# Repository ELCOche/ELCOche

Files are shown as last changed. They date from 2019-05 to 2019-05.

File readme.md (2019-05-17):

# ELCOche
This project has been created by:
 + Mª del Pilar Aguilera Manzanera
 + Enrique Calatayud Candelas
 + Guillermo González Martín
 + María Tejedor Rami

for the subject Electronica de Comunicaciones (ELCO) at Escuela Técnica Superior
de Ingenieros de Telecomunicación (ETSIT) in the Universidad Politécnica de Madrid (UPM).

ELCOche is an educational project for schools. Students will gain Arduino programming abilities and to manage periferic modules.
The project is divided in 3 parts; First one that consists on building the car from 3D printed piezes. Second one in which the steering wheel and throttle pedal will be built. Lastly the Arduinos will be programmed for both sides transmitter(Steering wheel) and receiver(car).

[Youtube Link](https://www.youtube.com/channel/UC2VEYSTPbVNYy6-K6MgkIWw/featured)

[Instructables post](https://www.instructables.com/id/ELCOche-Remote-Control-RC-Car-Controlled-by-a-Real/)

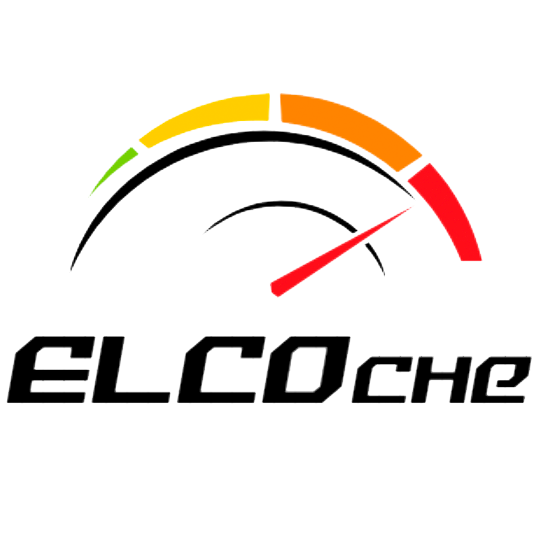
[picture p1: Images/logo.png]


[logo]: https://github.com/ELCOche/ELCOche/blob/master/Images/logo.png "Logo"

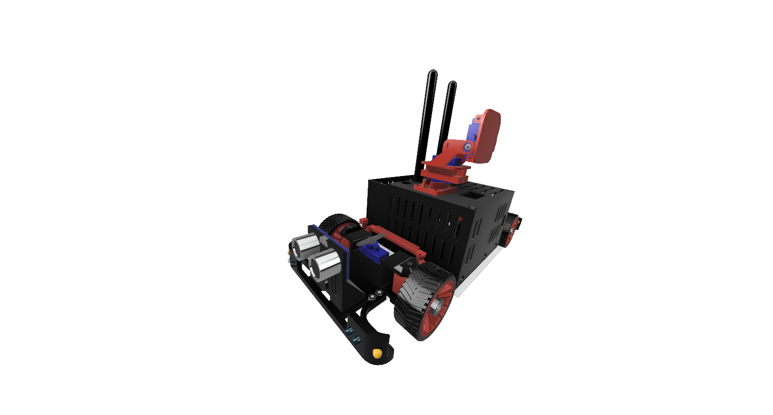
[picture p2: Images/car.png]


[car]: https://github.com/ELCOche/ELCOche/blob/master/Images/car.png "car"

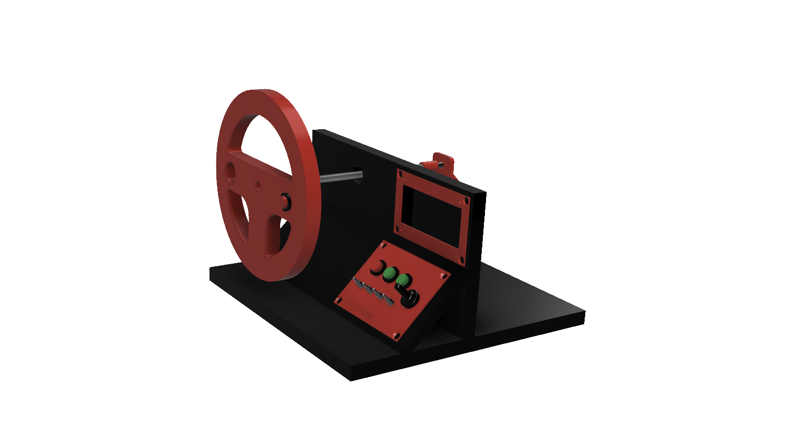
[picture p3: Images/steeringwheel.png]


[wheel]: https://github.com/ELCOche/ELCOche/blob/master/Images/steeringwheel.png "wheel"

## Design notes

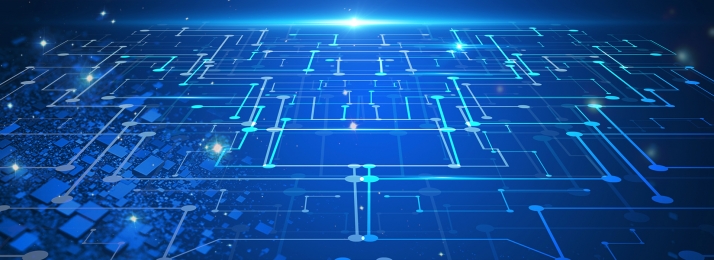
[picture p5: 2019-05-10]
Web Page/img/background/footer.jpg

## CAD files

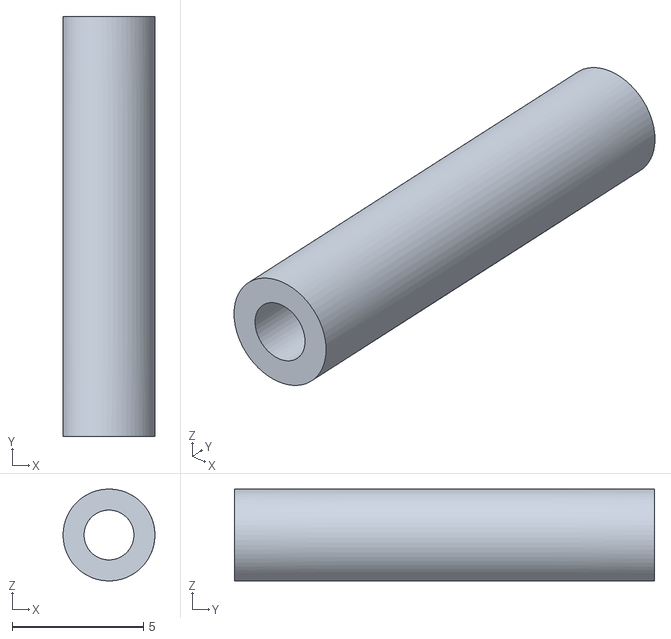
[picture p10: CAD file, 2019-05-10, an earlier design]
STL archives for 3D printing/Camera/adaptador.stl
3.50 x 16.0 x 3.50

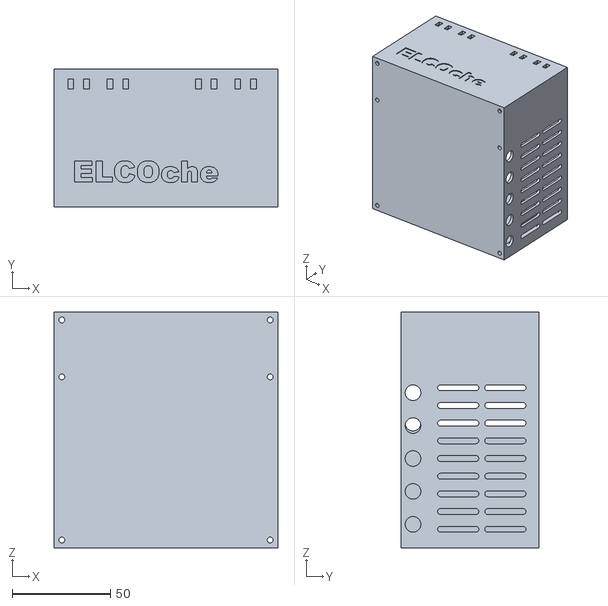
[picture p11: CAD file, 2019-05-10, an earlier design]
STL archives for 3D printing/Car/caja.stl
114.0 x 70.0 x 120.0

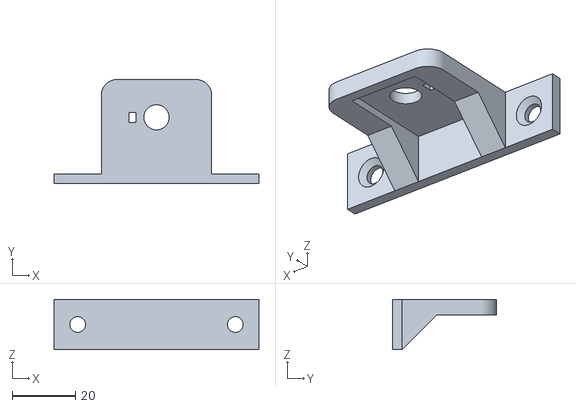
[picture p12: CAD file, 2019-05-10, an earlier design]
STL archives for 3D printing/Steering wheel/soporte_potenciometro.stl
65.0 x 33.0 x 16.0

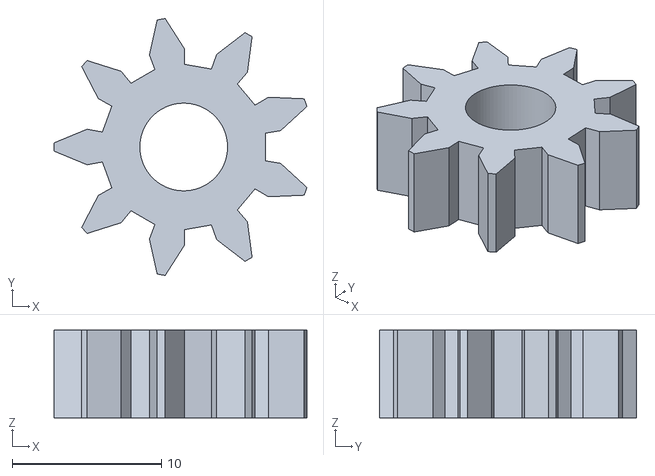
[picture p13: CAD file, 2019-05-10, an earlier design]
STL archives for 3D printing/Throttle/engranaje_potenciometro.stl
17.0 x 17.2 x 5.88

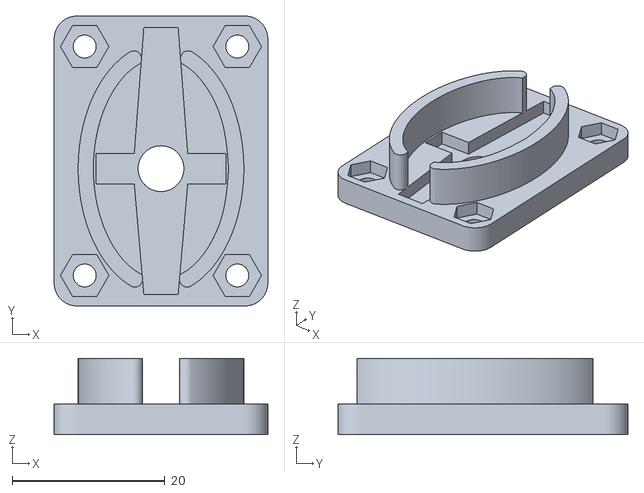
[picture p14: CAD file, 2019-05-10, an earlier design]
STL archives for 3D printing/Camera/base.stl
28.0 x 38.0 x 10.0

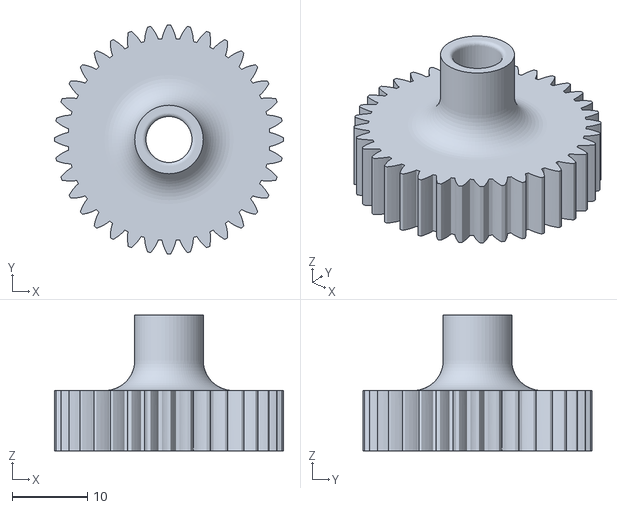
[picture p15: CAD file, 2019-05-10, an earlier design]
STL archives for 3D printing/Car/engranaje_eje.stl
30.4 x 30.4 x 18.0

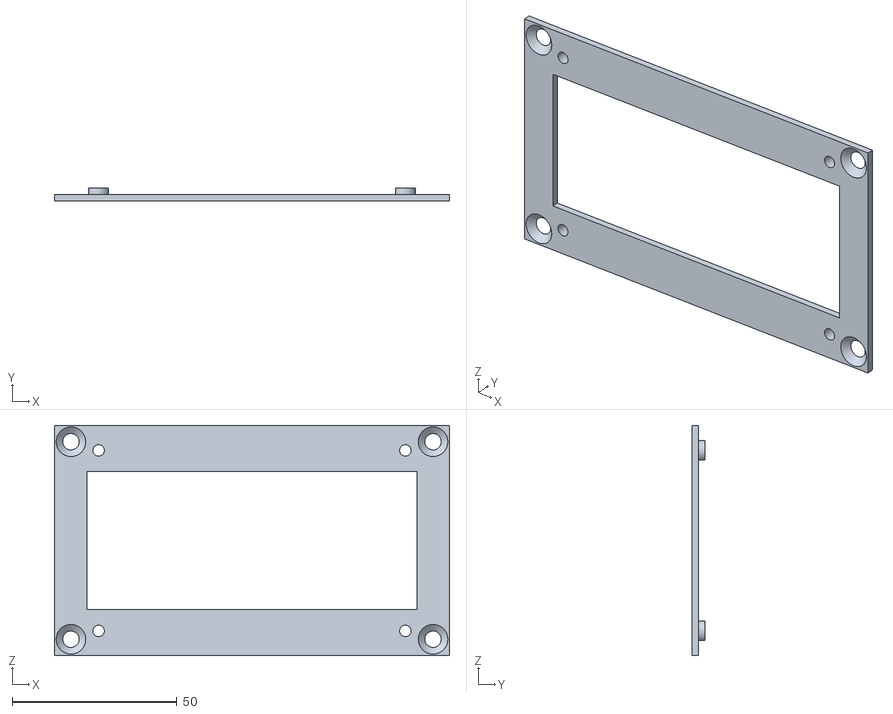
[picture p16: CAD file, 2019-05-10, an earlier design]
STL archives for 3D printing/Steering wheel/soporte_lcd.stl
120.0 x 4.00 x 70.0

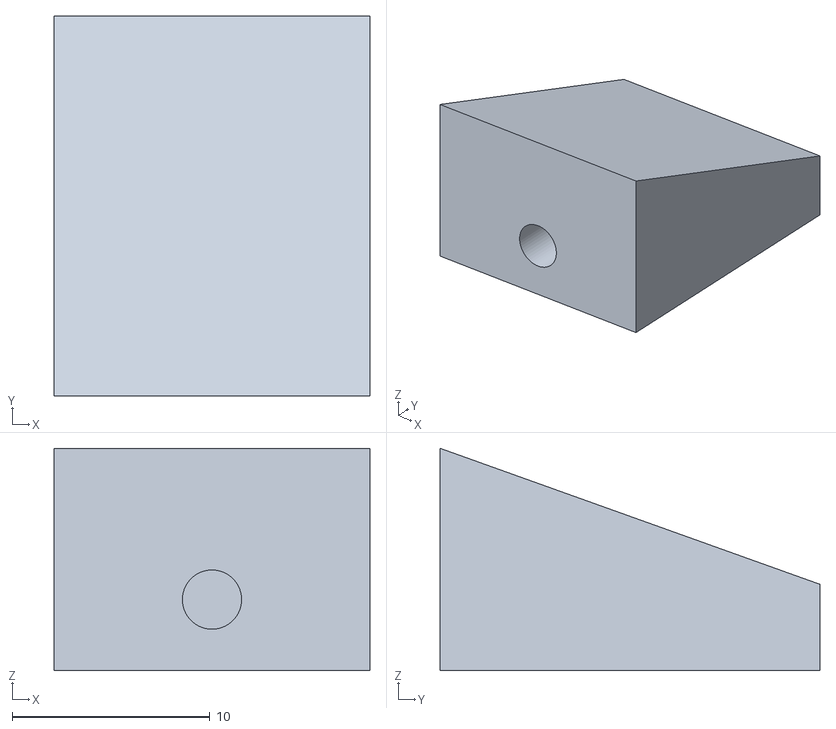
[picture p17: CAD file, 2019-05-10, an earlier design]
STL archives for 3D printing/Throttle/cuña.stl
16.0 x 19.2 x 11.3

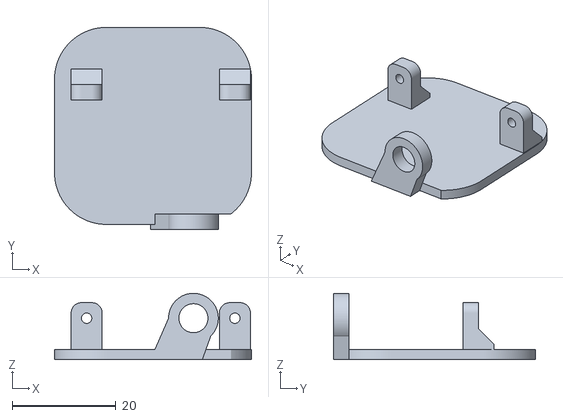
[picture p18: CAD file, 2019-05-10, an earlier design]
STL archives for 3D printing/Camera/superior.stl
38.0 x 39.0 x 12.8

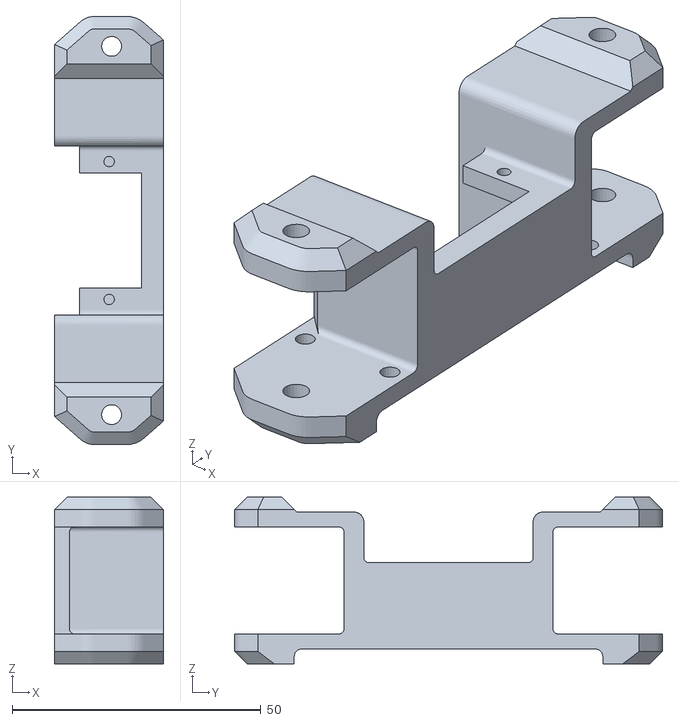
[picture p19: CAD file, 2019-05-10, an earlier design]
STL archives for 3D printing/Car/direccion.stl
21.9 x 86.0 x 33.5

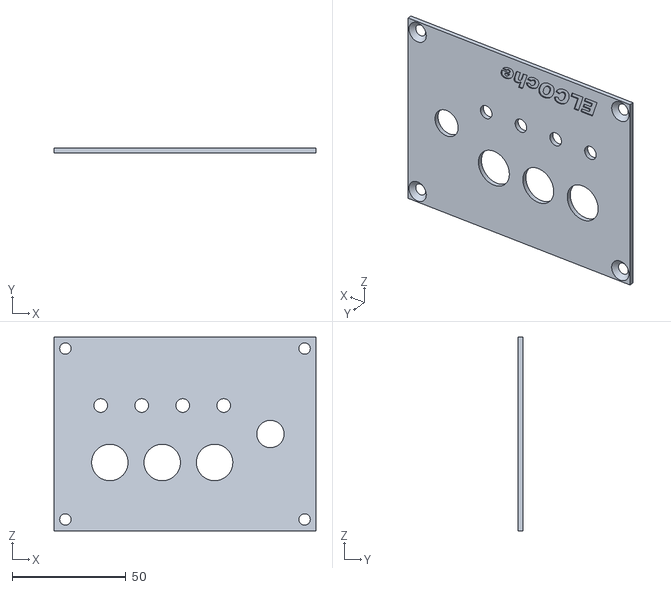
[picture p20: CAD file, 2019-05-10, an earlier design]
STL archives for 3D printing/Steering wheel/soporte_controles.stl
115.0 x 2.00 x 85.0

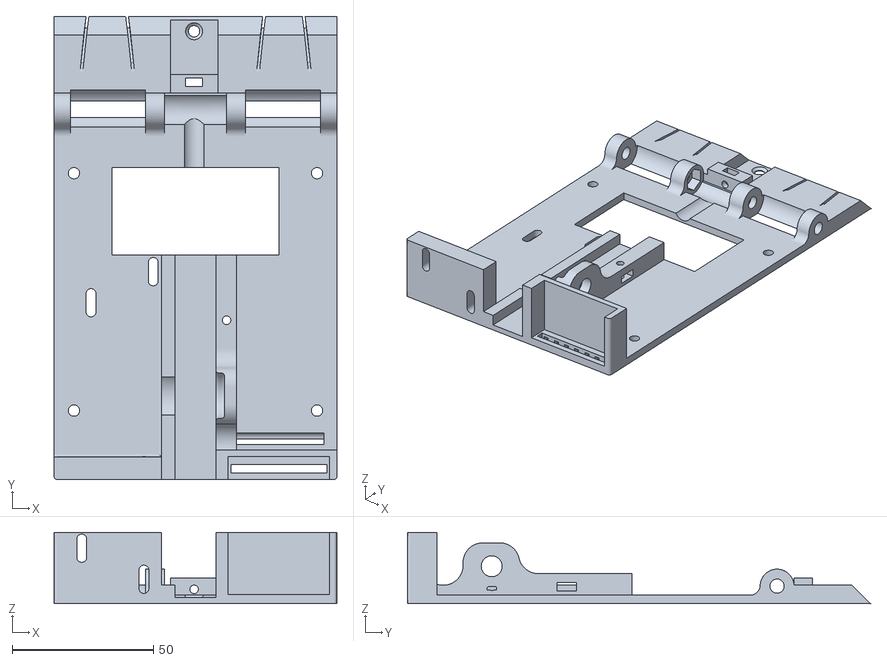
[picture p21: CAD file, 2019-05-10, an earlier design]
STL archives for 3D printing/Throttle/base.stl
100.0 x 163.8 x 25.2

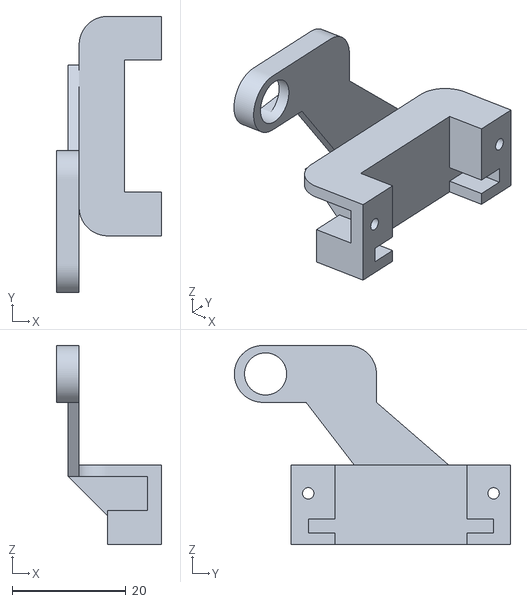
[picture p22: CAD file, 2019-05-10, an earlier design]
STL archives for 3D printing/Camera/brazo_derecho.stl
18.5 x 48.6 x 35.0

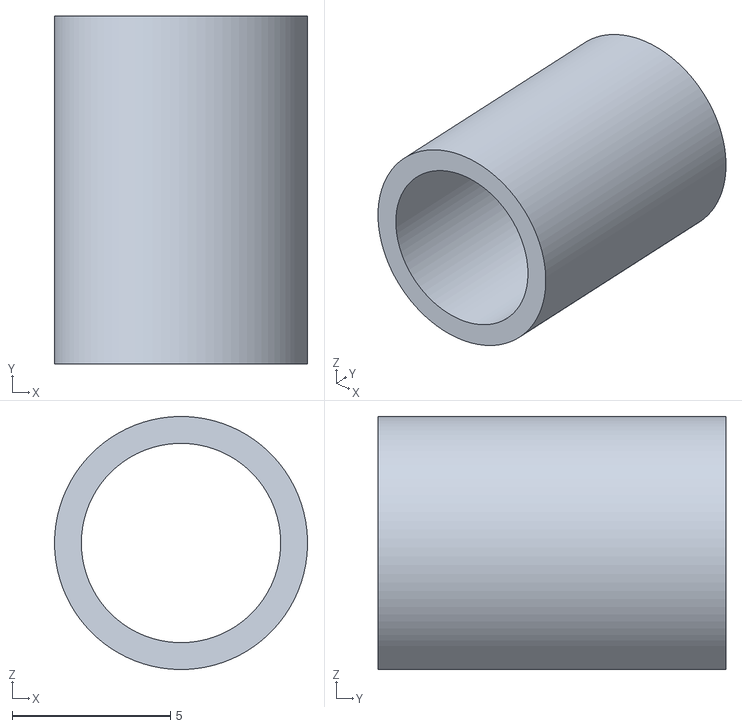
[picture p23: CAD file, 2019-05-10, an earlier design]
STL archives for 3D printing/Car/separador_rueda.stl
8.00 x 11.0 x 8.00

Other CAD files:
STL archives for 3D printing/Steering wheel/muelles.stl
STL archives for 3D printing/Throttle/brazo.stl
STL archives for 3D printing/Camera/brazo_izquierdo.stl
STL archives for 3D printing/Car/tope_rueda.stl
STL archives for 3D printing/Car/direccion_barra.stl
STL archives for 3D printing/Car/direccion_derecha.stl
STL archives for 3D printing/Car/direccion_izquierda.stl
STL archives for 3D printing/Car/direccion_objeto.stl
STL archives for 3D printing/Car/engranaje_motor.stl
STL archives for 3D printing/Car/parachoques_delantero.stl
STL archives for 3D printing/Car/parachoques_trasero.stl
STL archives for 3D printing/Car/rueda_delantera.stl
STL archives for 3D printing/Car/rueda_trasera.stl
STL archives for 3D printing/Car/soporte_eje_der.stl
STL archives for 3D printing/Car/soporte_eje_izq.stl
STL archives for 3D printing/Car/soporte_motor.stl
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

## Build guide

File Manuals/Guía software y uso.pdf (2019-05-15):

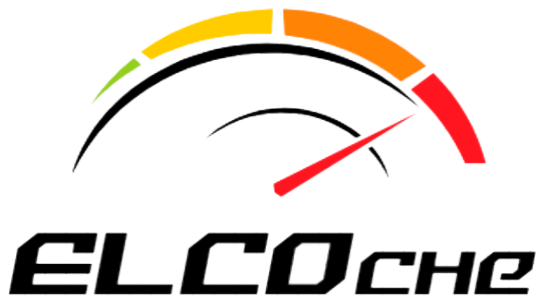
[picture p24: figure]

# Guía Software y Uso

ELCOche

## María del Pilar Aguilera Manzanera Enrique Calatayud Candelas Guillermo González Martín María Tejedor Rami

Guía de uso

## Índice de contenidos

Introducción | 3
Arduinos | 3
Programación del Transmisor | 3
Zona de configuración | 3
Envío de datos por radio | 4
Lectura de los potenciómetros | 4
Lectura de datos del acelerómetro (MPU-6050) | 5
Botones y switches | 6
Pantalla LCD | 7
Programación del Receptor | 8
Zona de configuración | 8
Recepción de datos por radio | 8
Movimiento motor | 10
Movimiento dirección | 11
Movimiento gimbal | 11
Botón de emergencia | 11
Luces del coche | 11
Sensor ultrasonido | 13
Claxon | 14
Cámara del coche | 14
Encendido y primeros pasos | 14

Guía de uso

## 1. Introducción

Guia del proyecto educativo ELCOche, diseñado para la asignatura Electrónica de consumo del Grado En Ingenieria De Tecnologias Y Servicios De Telecomunicación de la universidad Politécnica de Madrid. En la que se explica cómo realizar la programación del proyecto una vez completado el manual de montaje.

## 2. Arduinos

Para la realización de ELCOche se hace uso de dos Arduinos. Uno se encontrará en el coche y será el receptor. Se usa un Arduino Nano por su pequeño tamaño, ya que no se dispone de mucho espacio. Por otro lado, en la parte de control, se encuentra el transmisor. Se usa un Arduino Mega, ya que este dispone un mayor número de entradas y salidas digitales, a diferencia de otros modelos.
La definición y programación de los siguientes módulos no es una transcripción literal del código, hay cosas obviadas para dar sencillez a la lectura.

## 3. Programación del Transmisor

El transmisor se encuentra en la zona de control (volante, pedal y gafas) y se programa en un Arduino Mega.
Se divide el código según los diferentes bloques que lo componen:
a. Zona de configuración

Al principio del código se definen todas las constantes y los pines del Arduino a los que se van a conectar los módulos que se van a utilizar, para así poder ser modificadas con mayor facilidad en el caso de ser necesario.

b. Envío de datos por radio

Para hacer uso de las radios, se necesita importar la librería SoftwareSerial.h. Esta librería ha sido desarrollada para permitir comunicación serie por cualquier par de pines digitales. El Arduino tiene incorporados en los pines 0 y 1 este tipo de comunicación, pero se opta por usar la librería ya que si se usaran estos pines habría problemas al depurar (los mensajes mostrados en la consola del ordenador utilizan dichos pines)

Guía de uso

Para crear una comunicación serie en dos pines se utiliza la siguiente sentencia:

SoftwareSerial radio(PIN_RADIO_TX, PIN_RADIO_RX);

Las radios elegidas funcionan a 57600 baudios. Esto se indica en el | setup() | de la
siguiente forma:

radio.begin(RADIO_BAUDRATE);

Para el envío, se crea un string ‘data’ con todos los datos de control separados mediante comas. Para la decodificación de estos datos en el receptor, se envían caracteres de control (‘s’ - start y ‘e’ - end).

radio.print("s" + data + "e");

c. Lectura de los potenciómetros

En el transmisor se realiza la lectura de dos potenciómetros. Uno controla la dirección del coche y se encuentra en el volante, y el otro controla la velocidad del coche y se encuentra en el pedal.

Se definen los pines en la zona de configuración y se declaran como entrada en el
setup():

pinMode(PIN_MOTOR, INPUT);
pinMode(PIN_DIR, INPUT);

Se realiza una lectura analógica y se guarda el valor en una variable, haciendo previamente un mapeado para transformar los valores de lectura del potenciómetro (0 a 1023 ) en los adecuados para el motor (0 a 255) y dirección (60
1
a 120).

Para calcular la dirección es necesario realizar un calibrado previamente, en el que se mira cual es el valor del potenciómetro cuando el volante está en su posición de reposo (CEN_WHEEL), el valor que tiene cuando está completamente girado hacia la izquierda (MIN_WHEEL) y hacia la derecha (MAX_WHEEL).

1 El Arduino Mega posee conversores analógico-digitales de 10 bits (2

10 = 1024) en sus 16 (A0 - A15) entradas analógicas

Guía de uso

Se obtiene el mínimo de estos dos últimos valores, y se le suma y resta a la posición inicial, pasandoselos al map se pretende que se obtenga la dirección 90 cuando el volante esté en reposo, y que alcance 60 o 120 cuando esté completamente girado a cada uno de los sentidos.

También es necesario saber cual es valor máximo del potenciómetro al pisar completamente el pedal (MAX_PEDAL) y el mínimo cuando está en reposo (MIN_PEDAL).

int max_turn = min(abs(MIN_WHEEL - CEN_WHEEL), abs(MAX_WHEEL -CEN_WHEEL));

motor = map(analogRead(PIN_MOTOR), MIN_PEDAL, MAX_PEDAL, MIN_MOTOR, MAX_MOTOR);

dir = map(analogRead(PIN_DIR), CEN_WHEEL - max_turn, CEN_WHEEL + max_turn, MIN_DIR, MAX_DIR);

Además es recomendable asegurarse de que en caso de error del calibrado no se le pasa al motor o al servo un valor que no tenga sentido.

if (motor < 5) {
motor = 0;
}

if (dir > MAX_DIR) {
dir = MAX_DIR;
} else if (dir < MIN_DIR) { dir = MIN_DIR;
}
d. Lectura de datos del acelerómetro (MPU-6050)

En el transmisor se encuentran las gafas para controlar el gimbal en el coche. Esto se hace mediante un acelerómetro, el MPU-6050. Se conecta de la siguiente manera:

Guía de uso

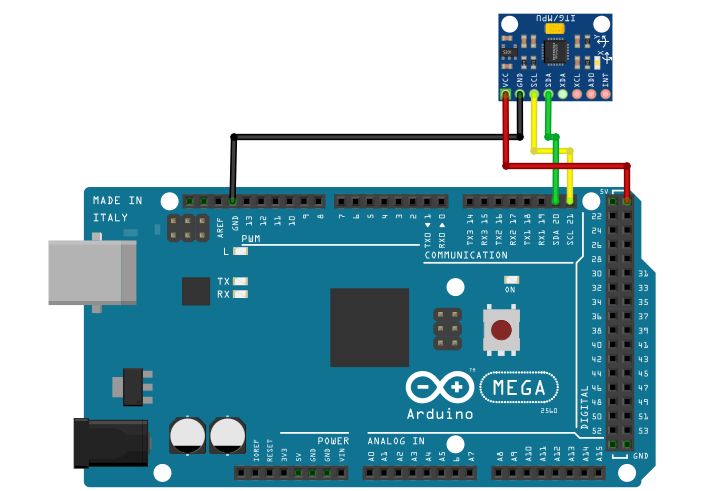
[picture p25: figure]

Para usarlo será necesario incluir la librería <MPU6050.h>. Se define el acelerómetro:

MPU6050 mpu;

Se inicializa en el setup():

while (!mpu.begin(MPU6050_SCALE_2000DPS, MPU6050_RANGE_2G)) { Serial.println("Could not find valid MPU6050 sensor, check wiring!"); lcd.clear();
lcd.setCursor(0, 0);
lcd.print(text_0);
lcd.setCursor(0, 1);
lcd.print("MPU ERROR!");
lcd.setCursor(0, 2);
lcd.print("Please, check wiring"); delay(500);
}
En cada ciclo del | loop() | se leen los datos de interés del acelerómetro, en nuestro
caso, el yaw (giro horizontal de la cabeza) y el pitch (giro vertical):

Vector norm = mpu.readNormalizeGyro();
yaw = yaw + norm.ZAxis * timeStep;
pitch = pitch + norm.YAxis * timeStep;

Guía de uso

e. Botones y switches

El volante dispone de un panel de control con diferentes botones y switches. En la zona de configuración se define a qué pin se corresponde cada uno de ellos y en
el | setup() | su modo de uso. Se definen como | INPUT_PULLUP | ya que cuando los
botones y switches no están accionados no se pueden quedar al aire.
pinMode(PIN_LEVER_D, | INPUT_PULLUP);
pinMode(PIN_LEVER_R, | INPUT_PULLUP);
pinMode(PIN_SW_LIGHTS_ON, | INPUT_PULLUP);
pinMode(PIN_SW_LIGHTS_AUTO, INPUT_PULLUP);
pinMode(PIN_SW_WARNINGS, | INPUT_PULLUP);
pinMode(PIN_SW_ULTRASONIC, | INPUT_PULLUP);
pinMode(PIN_BTN_STOP, | INPUT_PULLUP);
pinMode(PIN_BTN_CAL, | INPUT_PULLUP);
pinMode(PIN_BTN_CAL_MPU, | INPUT_PULLUP);
pinMode(PIN_BTN_CLAXON, | INPUT_PULLUP);
pinMode(PIN_SW_CAM, | INPUT_PULLUP);
Se realiza la lectura de cada uno de los pines con la función | readValue() | y
guardamos su valor, se utiliza esta función para en vez de enviar 0 o 1, que es el valor que se obtiene mediante digitalRead se cambie a los valores definidos en DATA_LOW (2) y DATA_HIGH (3), para así en receptor detectar con mayor facilidad que ha habido un fallo al enviarse:
lever_d = | readValue(PIN_LEVER_D);
lever_r = | readValue(PIN_LEVER_R);
sw_lights_on = | readValue(PIN_SW_LIGHTS_ON);
sw_lights_auto = readValue(PIN_SW_LIGHTS_AUTO);
sw_warnings = | readValue(PIN_SW_WARNINGS);
sw_ultrasonic = | readValue(PIN_SW_ULTRASONIC);
sw_cam = | readValue(PIN_SW_CAM);
btn_stop = | readValue(PIN_BTN_STOP);
btn_cal = | readValue(PIN_BTN_CAL);
btn_cal_mpu= | readValue(PIN_BTN_CAL_MPU);
btn_claxon = | readValue(PIN_BTN_CLAXON);

int readValue(int pin) {
return digitalRead(pin) ? DATA_LOW : DATA_HIGH; }

Guía de uso

Dependiendo de la posición del switch del control del gimbal se enviarán los datos recogidos por el acelerómetro o por el joystick.

if (sw_cam == 2) {
c_yaw = map(analogRead(PIN_JOY_X), 0, 1023, 0, 180); c_pitch = map(analogRead(PIN_JOY_Y), 0, 1023, 0, 180); } else {
c_yaw = map(yaw, -10, 10, 0, 180);
c_pitch = map(pitch, -10, 10, 0, 180);
}
f. Pantalla LCD

El volante dispone de una pantalla LCD para mostrar mensajes, que se conecta de la siguiente forma:

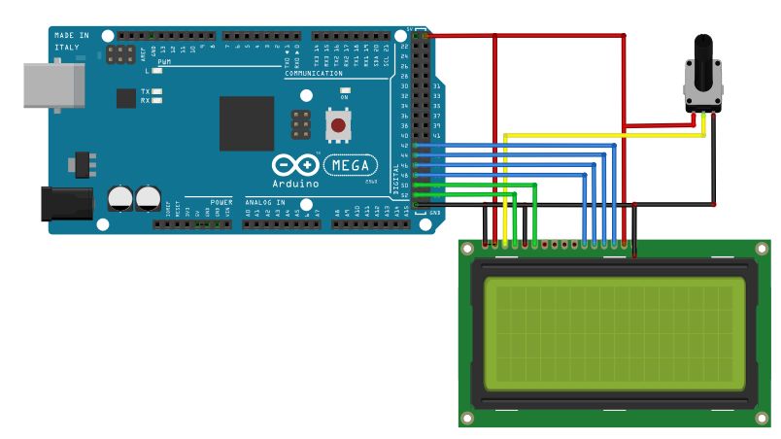
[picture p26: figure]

Para programar la pantalla, se hace uso de la librería | <LiquidCrystal.h> | de
Arduino.

Se definen los pines de la pantalla LCD en la zona de configuración y se inicializa en
el setup():

LiquidCrystal lcd(E, RS, D4, D5, D6, D7);

lcd.begin(COLS, ROWS);

Guía de uso

Para escribir en la pantalla se utilizan las siguientes funciones de la librería.

lcd.clear();
lcd.setCursor(0, 0);
lcd.print(text_0);
lcd.setCursor(0, 1);
lcd.print(text_1);

## 4. Programación del Receptor

El receptor se encuentra en el coche y se programa en un Arduino Nano. Se divide el código según los diferentes bloques que lo componen:

a. Zona de configuración

Tiene la misma función que la del transmisor.

b. Recepción de datos por radio

Una de las dos radios está diseñada para ser utilizada mediante un USB, por lo tanto para poder conectarla al arduino es necesario soldar en su placa los cables necesarios para tener TX, RX, VCC y GND.

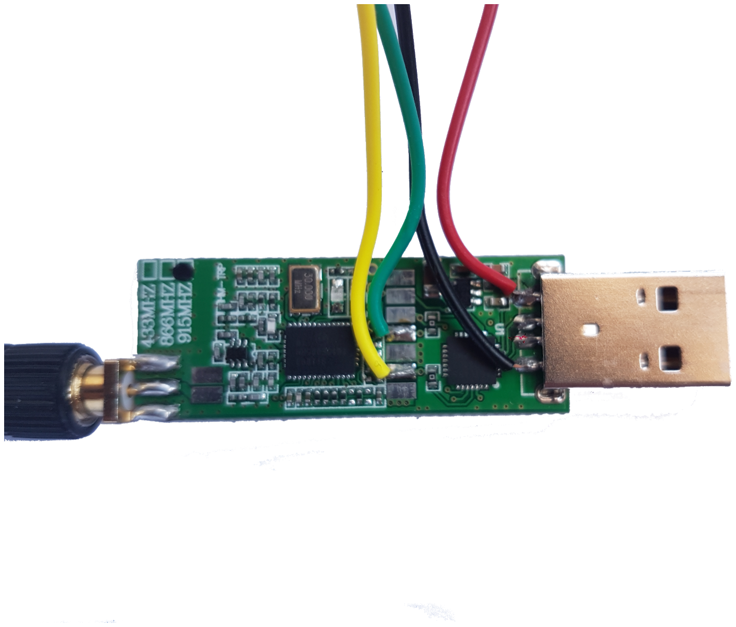
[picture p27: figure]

Guía de uso

Para programarlas se hace uso de la librería <SoftwareSerial.h>. Esta librería ha sido desarrollada para permitir comunicación serie por cualquier par de pines digitales. El Arduino tiene incorporados en los pines 0 y 1 este tipo de comunicación, pero se opta por usar la librería ya que si se usaran estos pines habría problemas al depurar (los mensajes mostrados en la consola del ordenador utilizan dichos pines) Para crear una comunicación serie en dos pines se utiliza la siguiente sentencia:

SoftwareSerial radioSerial(PIN_RADIO_TX, PIN_RADIO_RX);

Las radios elegidas funcionan a 57600 baudios por tanto se fija su uso a estos baudios en el setup():

radioSerial.begin(RADIO_BAUDRATE);

Se comprueba que haya datos disponibles para proceder a su lectura. Para decodificarlos se buscan los caracteres ‘s’ y ‘e’, que marcan el inicio y el fin de un bloque, respectivamente.

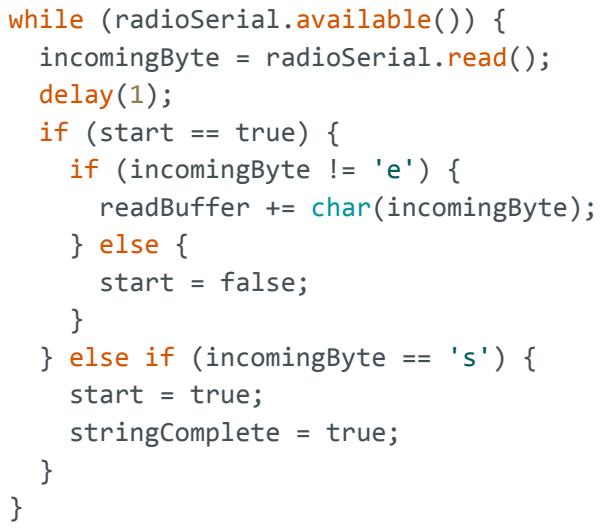
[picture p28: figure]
while (radioSerial.available()) { incomingByte = radioSerial.read(); delay(1); if (start == true) { if (incomingByte != 'e') { readBuffer += char(incomingByte); } else { start = false;; } } else if (incomingByte == 's') { start = true; stringComplete = true;

Una vez completado el string, se separan y se almacenan los datos en un array de números enteros, mediante la función string_data(). Haciendo uso de check_values(), se comprueba que los valores recibidos están dentro de unos intervalos, para detectar errores de envío, si son correctos se asignan a las variables correspondientes, cambiando previamente los que en el receptor fueron modificados por DATA_LOW (2) y DATA_HIGH (3), por 0 y 1, respectivamente.

Guía de uso

void string_data(String sdata){
for (int i = 0; i < DATA_LENGTH; i++) {
int index = sdata.indexOf(separator); data[i] = sdata.substring(0, index).toInt(); sdata = sdata.substring(index + 1);
}
}

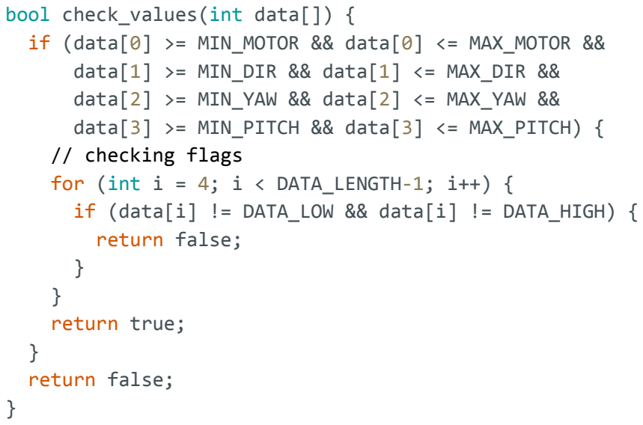
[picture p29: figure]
bool check_values(int data[]) {; // checking flags; return false;; } return true;; } return false;

if (data[0] >= MIN_MOTOR && data[0] <= MAX_MOTOR && data[1] >= MIN_DIR && data[1] <= MAX_DIR && data[2] >= MIN_YAW && data[2] <= MAX_YAW && data[3] >= MIN_PITCH && data[3] <= MAX_PITCH) {

for (int i = 4; i < DATA_LENGTH-1; i++) {
if (data[i] != DATA_LOW && data[i] != DATA_HIGH) {

En el caso de que el receptor dejase de recibir datos durante más de 1 segundo, se para el motor para evitar posibles accidentes.

unsigned long currentMillis = millis();
if ((unsigned long)(currentMillis - prevMillisSignal) >= intervalNoSignal) {
while (!radioSerial.available()) { analogWrite(PIN_ME, 0);
}
}

Guía de uso

c. Movimiento motor

Para mover el motor de corriente continua es necesario hacer uso del controlador L298N, que además tiene una salida de 5V utilizada para alimentar el arduino. Se alimenta todo con una batería de 12V, a la que también se conecta un regulador DC-DC con el que se obtienen 5V para alimentar los servos y la radio, ya que si se conectaran directamente al arduino no les llegaría suficiente corriente.

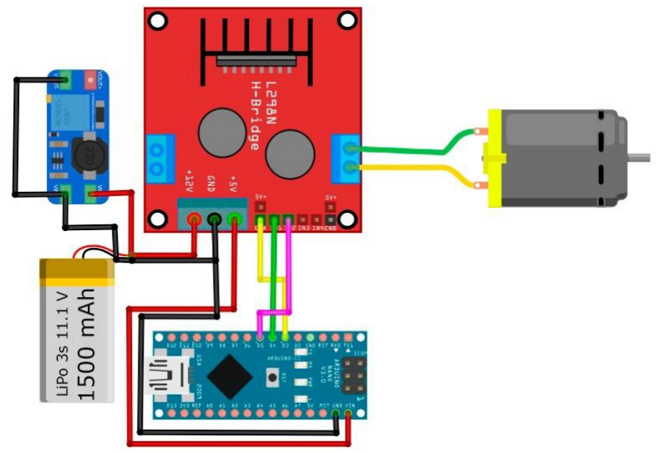
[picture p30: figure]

Tiene tres pines de entrada que se inicializan en el setup():

pinMode(PIN_ME, OUTPUT);
pinMode(PIN_M1, OUTPUT);
pinMode(PIN_M2, OUTPUT);

Mediante la función analogWrite se controla la velocidad del motor y en función de la posición del switch se hará que el coche vaya marcha adelante (lever_d), marcha atrás(lever_r) o que se quede parado.

Guía de uso

analogWrite(PIN_ME, motor);

if (lever_d) {
digitalWrite(PIN_M1, HIGH); digitalWrite(PIN_M2, LOW); } else if (lever_r) {
digitalWrite(PIN_M1, LOW); digitalWrite(PIN_M2, HIGH); } else {
digitalWrite(PIN_M1, LOW); digitalWrite(PIN_M2, LOW); }
d. Movimiento dirección

Para el control del servo de dirección, se necesita la librería <Servo.h> de Arduino.

Se inicializa el servo:

Servo servo_dir;
servo_dir.detach();
servo_dir.attach(PIN_DIR);
Se realiza el | detach() | y | attach() | cada vez para eliminar las interrupciones que se
producen en los servos. Se escribe el valor enviado por el transmisor para el movimiento del servo:

servo_dir.write(dir);

e. Movimiento gimbal

Para evitar problemas de interrupciones, los dos servos que controlan la cámara no se programan con la librería servo. Se mueven mediante el siguiente método, al que se le pasa el pin y el ángulo del servo que se quiere move:

void moverServo(int pin, int angulo){
float pausa;
pausa = angulo * 2000.0/180.0 + 700; digitalWrite(pin, HIGH);

Guía de uso

delayMicroseconds(pausa);
digitalWrite(pin, LOW);
delayMicroseconds(25000-pausa); }

moverServo(PIN_CAM_YAW, c_yaw); moverServo(PIN_CAM_PITCH, c_pitch);

f. Botón de emergencia

Si el botón de emergencia es pulsado el coche se queda parado durante 10 segundos, poniendo un delay al programa. Esta función puede ser modificada para realizar otras funciones como que el coche pare hasta que se reinicie o que se produzca un pitido del claxon continuo.

g. Luces del coche

En el coche se hace uso de leds de 5 mm para diferentes funciones: luces de cruce (delanteras y traseras), luces de emergencia (podrían ser usadas como intermitentes) y luces de marcha atrás. Además, tiene un sensor de luz, que se conecta con una resistencia (alrededor de 1.5 kΩ) realizando un divisor de tensión. Por lo tanto, la entrada analógica A6 leerá un valor idealmente entre 0 (ausencia de luz, resistencia LDR = infinito) y 1023 (mucha luz, resistencia LDR = 0).

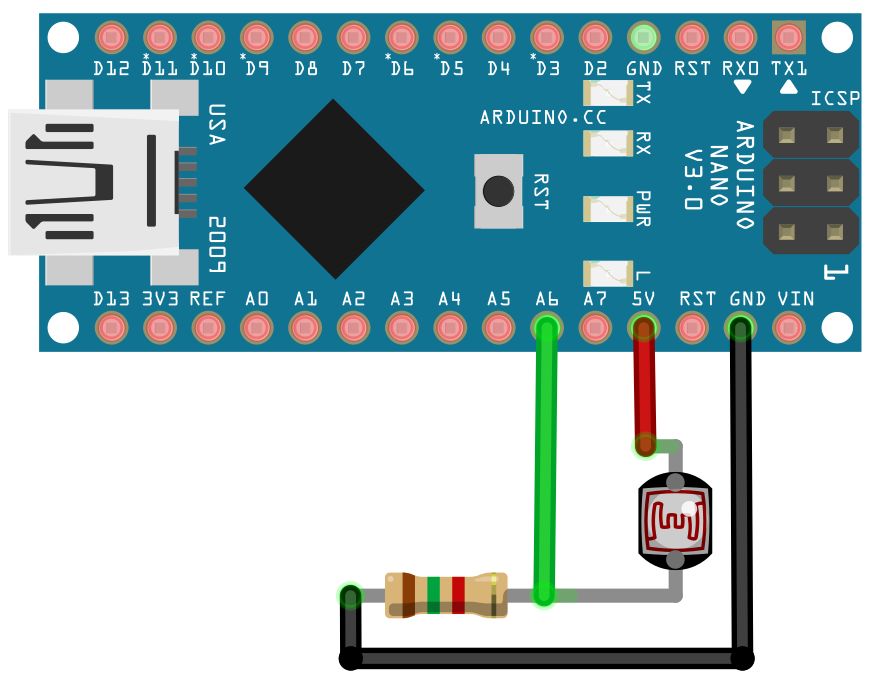
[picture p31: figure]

Guía de uso

Se definen los pines en la zona de configuración y en el setup() se declaran como salida.

pinMode(PIN_LIGHT_F1, OUTPUT); // Front left headlights pinMode(PIN_LIGHT_F2, OUTPUT); // Front right headlights pinMode(PIN_LIGHT_B1, OUTPUT); // Back headlights pinMode(PIN_LIGHT_R1, OUTPUT); // Reverse headlights pinMode(PIN_LIGHT_W1, OUTPUT); // Front left warning lights pinMode(PIN_LIGHT_W2, OUTPUT); // Front right warning lights
pinMode(PIN_LDR, INPUT); | // Sensor de luz

Según los valores recibidos se procede al encendido o apagado de las luces, para lo cual se hace uso de la función checkControls(), que enciende las luces delanteras y las traseras si el switch está activo en la posición lights_on, o en la posición lights_auto si la luz que percibe el sensor es menor a un umbral. También hace parpadear las luces de warnings mediante el método blink_lights(). Además al mover el motor marcha atrás se activan las luces LIGHT_R1 , y cuando se pulsa el botón de emergencia las de warnings.

void checkControls() {
if ((sw_lights_auto && checkLightIntensity()) || sw_lights_on) { digitalWrite(PIN_LIGHT_F1, HIGH); // Front left headlights digitalWrite(PIN_LIGHT_F2, HIGH); // Front right headlights digitalWrite(PIN_LIGHT_B1, HIGH); // Back headlights
} else {
digitalWrite(PIN_LIGHT_F1, LOW); // Front left headlights digitalWrite(PIN_LIGHT_F2, LOW); // Front right headlights digitalWrite(PIN_LIGHT_B1, LOW); // Back headlights
}

if (sw_warnings) {
blink_lights(); | // Function that blink lights
} else {
digitalWrite(PIN_LIGHT_W1, LOW); // Front left warning lights digitalWrite(PIN_LIGHT_W2, LOW); // Front right warning lights }
}

void blink_lights() {
unsigned long currentMillis = millis();

Guía de uso

if ((unsigned long)(currentMillis - prevMillisBlink) >= intervalWarn){ state_warning = !state_warning;
digitalWrite(PIN_LIGHT_W1, state_warning); digitalWrite(PIN_LIGHT_W2, state_warning);
prevMillisBlink = millis();
}
}
h. Sensor ultrasonido

El coche dispone de un sensor de ultrasonidos que es programado mediante la librería <NewPing.h>, y se conecta de la siguiente forma:

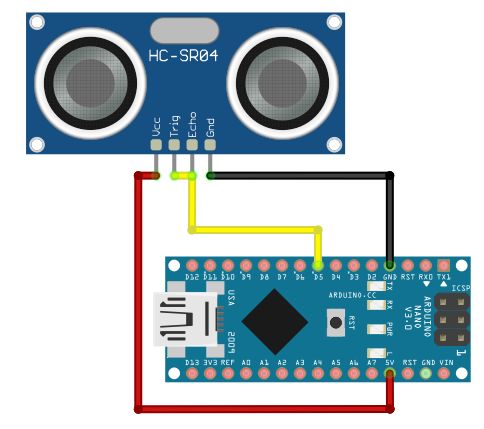
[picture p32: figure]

En la zona de configuración se inicializa:

NewPing sonar(PIN_ULTRASONIC, PIN_ULTRASONIC, MAX_DISTANCE);

Si se detecta un obstáculo a una distancia que esté entre MAX_DIST_BRAKE y MIN_DIST_BRAKE, no permite que el coche vaya marcha adelante. Se ha definido una distancia mínima para evitar que cuando el sensor falle y detecte una distancia 0 se pare el coche.

dist = sonar.ping_cm();

Guía de uso

if (lever_d && dist < MAX_DIST_BRAKE && dist > MIN_DIST_BRAKE) { Serial.println("!!!------------------------!!!"); Serial.println("!!!----EMERGENCY BRAKE!----!!!"); Serial.println("!!!------------------------!!!"); analogWrite(PIN_ME, 0);
}
i. Claxon
Para hacer uso del buzzer se utilizan las funciones | tone() | y | noTone(). Si no se
modifica la librería para controlar el sensor de ultrasonidos, se genera un conflicto, por lo que las soluciones son modificar la librería (Cambiar el valor de
TIMER_ENABLED = false | en | <NewPing.h>) o usar otra librería para controlar el
buzzer.

Se declara el pin del buzzer y la frecuencia del sonido en la zona de configuración y se declara como salida en el setup(). Se activar el zumbador en caso de que el botón se haya pulsado.

if (btn_claxon) {
tone(PIN_CLAXON, FREC_CLAXON); } else {
noTone(PIN_CLAXON);
}

## 5. Cámara del coche

Se utiliza un sistema de comunicaciones independiente. Se trata de una cámara FPV, que tiene su propio transmisor y receptor. El receptor (EACHINE R051 está diseñado para que simplemente conectándolo a un móvil haciendo uso de la aplicación EACHINE, disponible en Android e iOS, se pueda ver lo que la cámara está emitiendo. El emisor (TS832S) se conecta directamente a la cámara y a una fuente de 12 VDC (se conecta directamente a la batería del coche).
El sistema funciona a una frecuencia de 5.8 GHz.

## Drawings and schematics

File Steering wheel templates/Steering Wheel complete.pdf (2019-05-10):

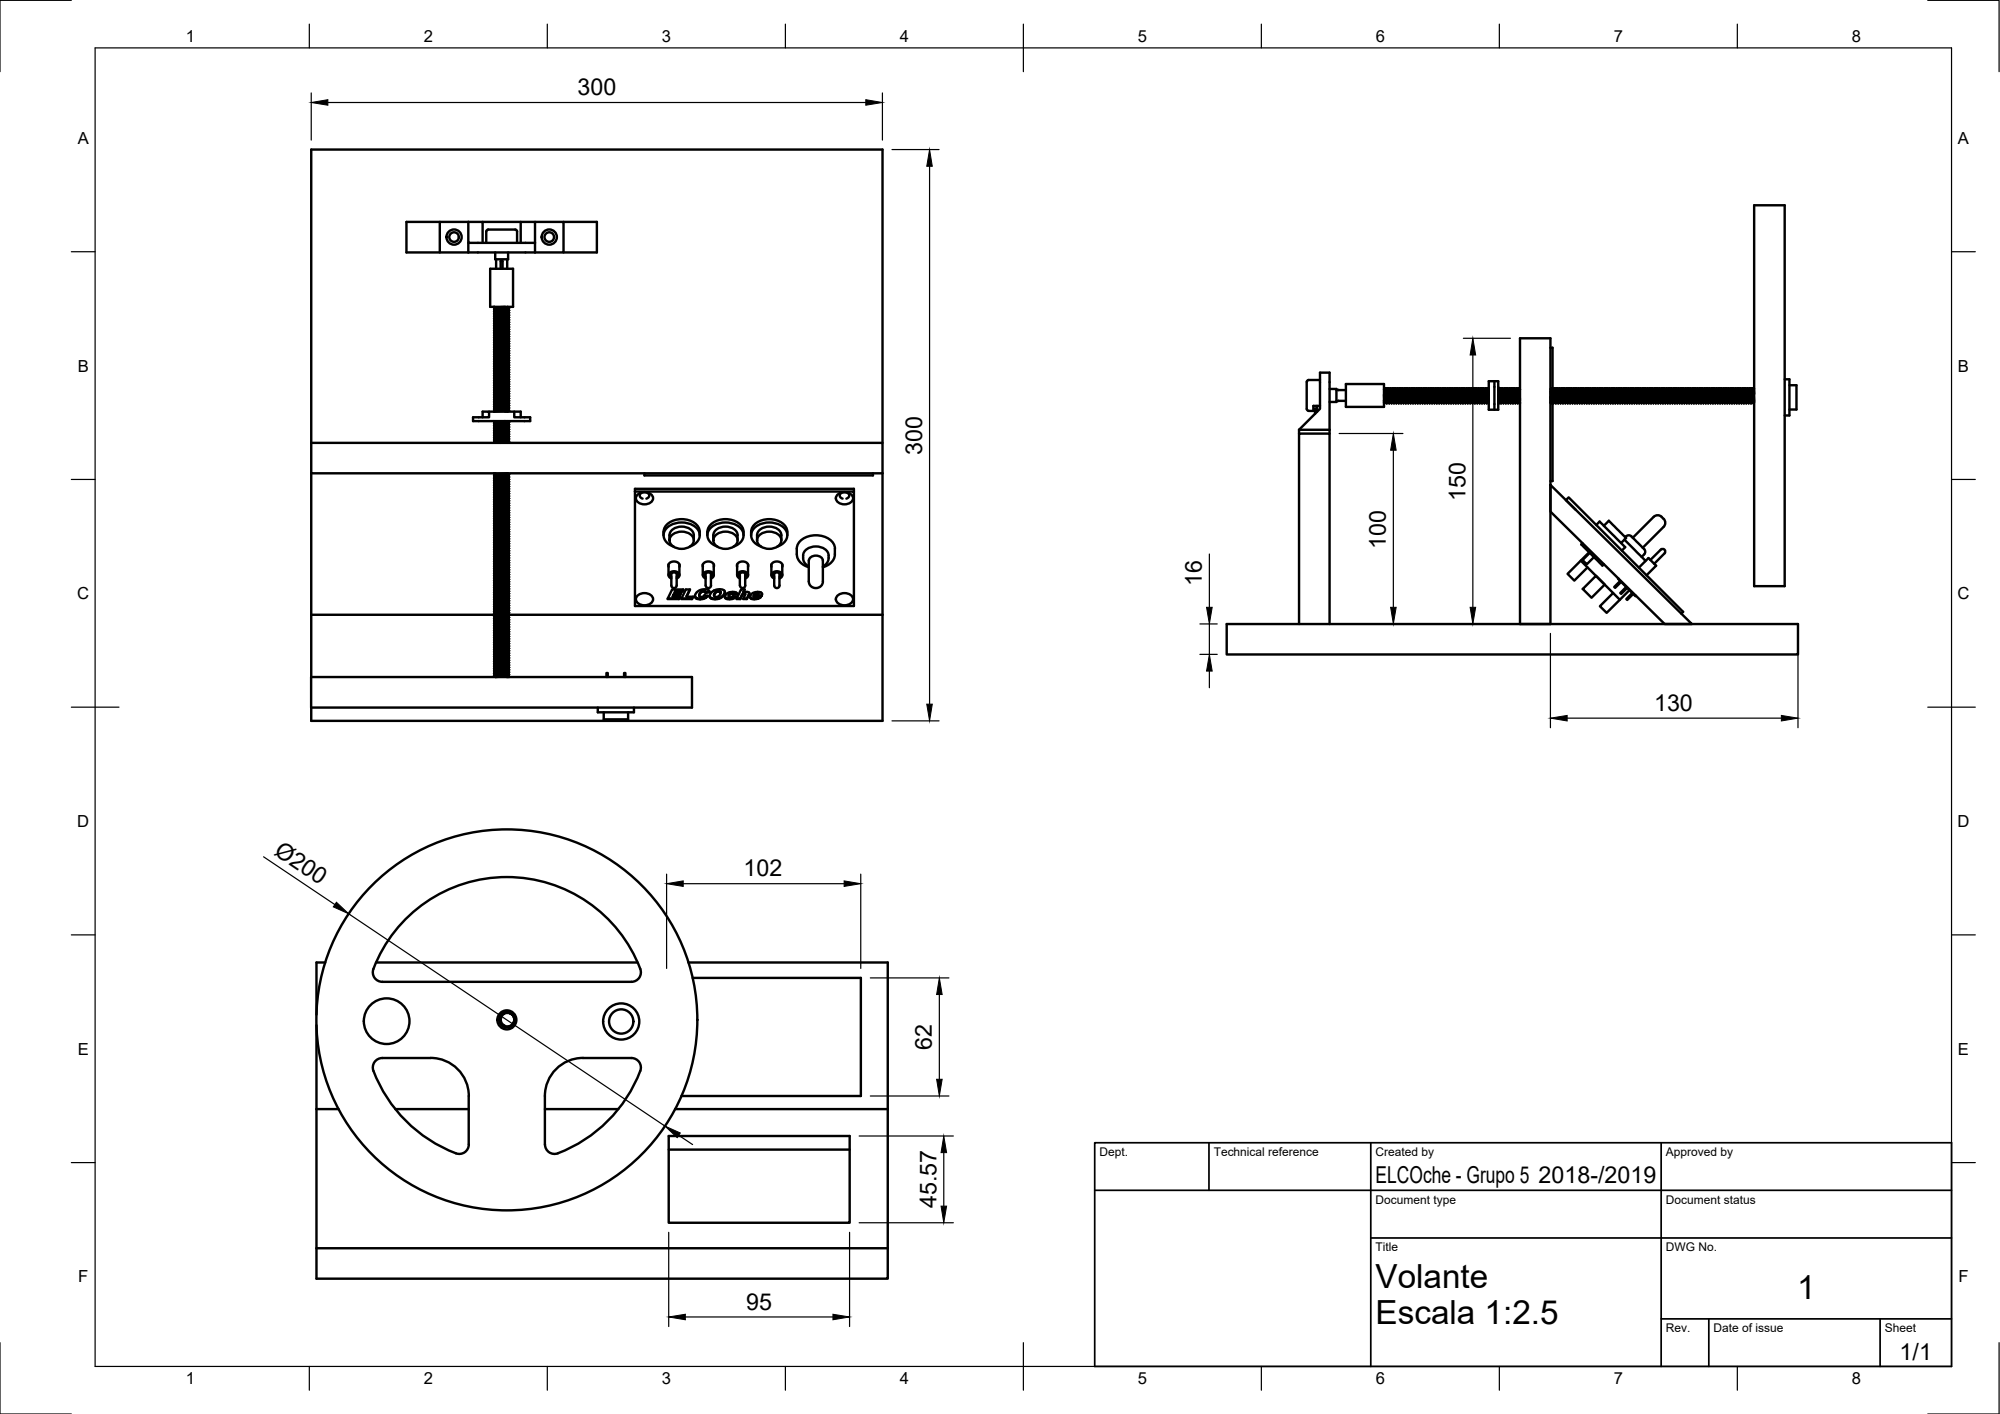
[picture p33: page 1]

Dept. | Technical reference | Created by ELCOche - Grupo 5 2018-/2019 | Approved by

Document type | Document status

Title Escala 1:2.5 | DWG No. 1 Volante

Rev. | Date of issue | Sheet 1/1

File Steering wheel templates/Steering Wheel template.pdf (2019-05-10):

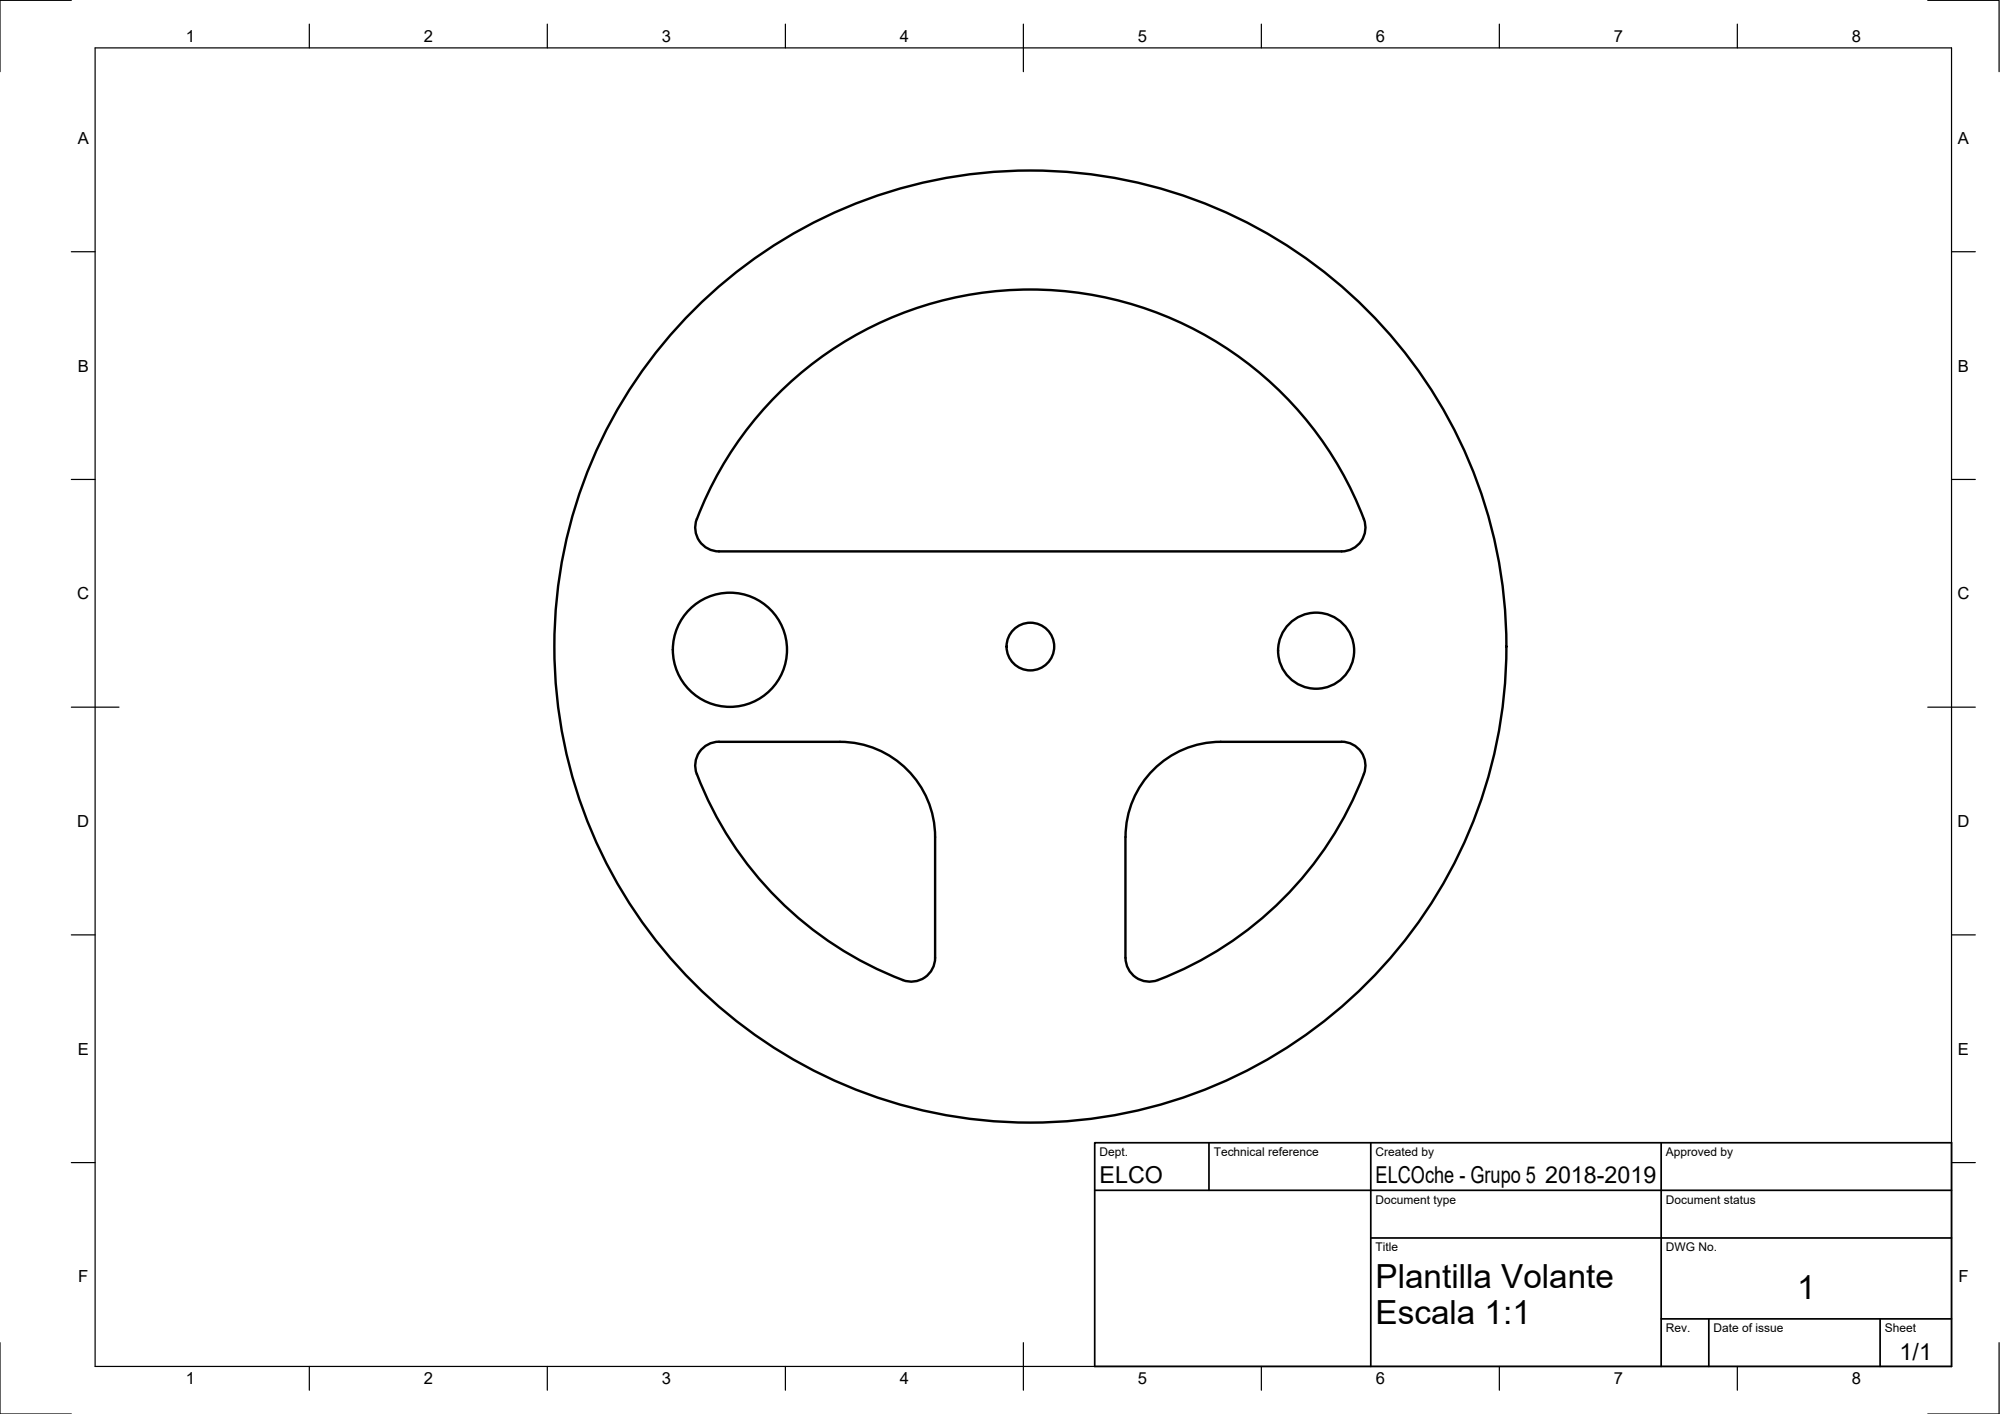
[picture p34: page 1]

Dept. ELCO | Technical reference | Created by ELCOche - Grupo 5 2018-2019 | Approved by

Document type | Document status

Title Escala 1:1 | DWG No. 1 Plantilla Volante

Rev. | Date of issue | Sheet 1/1

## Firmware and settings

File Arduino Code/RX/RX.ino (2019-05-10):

/*
 * ELCOche
 * 
 * This project has been created by:
 * - Mª del Pilar Aguilera Manzanera
 * - Enrique Calatayud Candelas
 * - Guillermo González Martín
 * - María Tejedor Rami
 * for the subject Electronica de Comunicaciones (ELCO) at Escuela Técnica Superior
 * de Ingenieros de Telecomunicación (ETSIT) in the universidad Politécnica de Madrid (UPM).
 *  
 * In this file you can find the code for the System Receptor (car).
 * The refered components are:
 * - Arduino Nano
 * - Receptor (o transceptor) of radio with serial communication
 * - Bridge in H (L298N)
 * - Motor DC (12V)
 * - 3 servomotors
 * - LEDs
 * - Buzzer
 * - Proximity sensor (HC-SR04)
 * - Photoresistor (LDR)
 */

// Libraries
#include <SoftwareSerial.h>
#include <Servo.h>
#include <NewPing.h>
/* tone() has conflicts NewPing.h. There are two solutions:
 *  1. Use another library to use the buzzer.
 *  2. Set TIMER_ENABLED = false in NewPing.h
 *  Uncomment the following line if 1.
 */
//#include <TimerFreeTone.h>

// Configuration
/*
 * You can change all the parameters of the RX in this section.
 */
#define SERIAL_BAUDRATE 9600
#define RADIO_BAUDRATE  57600
#define DATA_LENGTH     12
#define MIN_MOTOR       -255
#define MAX_MOTOR       255
#define MIN_DIR         60
#define MAX_DIR         120
#define MIN_YAW         -1000
#define MAX_YAW         1000
#define MIN_PITCH       -1000
#define MAX_PITCH       1000
#define MAX_DISTANCE    200
#define MIN_DIST_BRAKE  5
#define MAX_DIST_BRAKE  20
#define LDR_THRESHOLD   500
#define FREC_CLAXON     2000
#define DATA_HIGH       3
#define DATA_LOW        2
#define INTERVAL_WARN   500
#define INTERVAL_NO_SIG 1000

#define PIN_RADIO_TX    10
#define PIN_RADIO_RX    11
#define PIN_ME          3
#define PIN_M1          4
#define PIN_M2          5
#define PIN_DIR         8
#define PIN_CAM_YAW     6
#define PIN_CAM_PITCH   7
#define PIN_CLAXON      13
#define PIN_ULTRASONIC  9
#define PIN_LIGHT_F1    A0
#define PIN_LIGHT_F2    A1
#define PIN_LIGHT_B1    A2
#define PIN_LIGHT_R1    A3
#define PIN_LIGHT_W1    A4
#define PIN_LIGHT_W2    A5
#define PIN_LDR         A6

unsigned long intervalWarn =      INTERVAL_WARN;
unsigned long intervalNoSignal =  INTERVAL_NO_SIG;
unsigned long prevMillisBlink;
unsigned long prevMillisSignal;

int motor, dir, c_yaw, c_pitch;
bool lever_d, lever_r, sw_lights_on, sw_lights_auto, sw_warnings, sw_ultrasonic,  btn_stop, btn_claxon;
bool state_warning = LOW;
int dist, ldr;
int old_s_dir = 0;

bool stringComplete = false;
int data[DATA_LENGTH];
const char separator = ',';
char incomingByte;
String readBuffer = "";

SoftwareSerial radioSerial(PIN_RADIO_TX, PIN_RADIO_RX);
NewPing sonar(PIN_ULTRASONIC, PIN_ULTRASONIC, MAX_DISTANCE);
Servo servo_dir;

void setup() {
  Serial.begin(SERIAL_BAUDRATE);
  radioSerial.begin(RADIO_BAUDRATE);
  
  pinMode(PIN_CAM_YAW, OUTPUT);
  digitalWrite(PIN_CAM_YAW, LOW);
  pinMode(PIN_CAM_PITCH, OUTPUT);
  digitalWrite(PIN_CAM_PITCH, LOW);

  pinMode(PIN_ME,           OUTPUT);
  pinMode(PIN_M1,           OUTPUT);
  pinMode(PIN_M2,           OUTPUT);
  pinMode(PIN_LIGHT_F1,     OUTPUT);
  pinMode(PIN_LIGHT_F2,     OUTPUT);
  pinMode(PIN_LIGHT_B1,     OUTPUT);
  pinMode(PIN_LIGHT_R1,     OUTPUT);
  pinMode(PIN_LIGHT_W1,     OUTPUT);
  pinMode(PIN_LIGHT_W2,     OUTPUT);
  pinMode(PIN_LDR,          INPUT);

  prevMillisBlink = millis();
  prevMillisSignal = millis();
}
 
void loop() {
  bool start = false;
  readBuffer = "";
  servo_dir.detach();
  servo_dir.attach(PIN_DIR);
  dist = sonar.ping_cm();
  ldr = analogRead(PIN_LDR);

  /*
   * Checking if a switch or button has been pressed on the TX.
   */
  checkEmergency();
  checkObstacle();
  checkLever();
  checkControls();

  /*
   * Checking if the connection has been lost. In this case, warning lights blink and the motor stops. 
   */
  unsigned long currentMillis = millis();
  if ((unsigned long)(currentMillis - prevMillisSignal) >= intervalNoSignal) {
    while (!radioSerial.available()) {
      analogWrite(PIN_ME, 0);
      blink_lights();
    }
  }

  /*
   * Receiving data from the TX.
   */
  while (radioSerial.available()) {
    prevMillisSignal = millis();
    incomingByte = radioSerial.read(); 
    delay(1);
    if (start == true) {
      if (incomingByte != 'e') {
        readBuffer += char(incomingByte);
      } else {
        start = false;
      }
    } else if (incomingByte == 's') {
      start = true;
      stringComplete = true;
    }
  }

  /*
   * If the data string has arrived, we proceed and read it. 
   */
  if (stringComplete) {
    
    /*Debug
     * Serial.print("Data received: ");
     * Serial.println(readBuffer);
     */
    
    string_data(readBuffer);

    /*
     * Checking if the string is valid.
     */
    if (check_values(data)) {
      motor =           data[0];
      dir =             data[1];
      c_yaw =           data[2];
      c_pitch =         data[3]; 
      lever_d =         readValue(data[4]);
      lever_r =         readValue(data[5]);
      sw_lights_on =    readValue(data[6]);
      sw_lights_auto =  readValue(data[7]);
      sw_warnings =     readValue(data[8]);
      sw_ultrasonic =   readValue(data[9]);
      btn_stop =        readValue(data[10]);
      btn_claxon =      readValue(data[11]);

      /*
       * Writting in servo only if the current value is different of the old one.// writting in servo? no es wrriting a servo
       */
      if (old_s_dir != dir) {
        servo_dir.write(dir);
        old_s_dir = dir;
      }
      
      analogWrite(PIN_ME, motor);
      move_servo(PIN_CAM_YAW, c_yaw);
      move_servo(PIN_CAM_PITCH, c_pitch);
      printLogs();
    } else {
      Serial.print("Reception ERROR!: ");
      for (int i = 0; i < DATA_LENGTH-1; i++) {
        Serial.print(data[i]);
        Serial.print(", ");
      }
      Serial.println();
    }
  }
  stringComplete = false;
}

/*
 * Function that converts the number that means 'high' to '1' and
 * the number that means 'low' to '0'.
 */
bool readValue(int data) {
  return data == DATA_HIGH ? HIGH : LOW;
}

/*
 * Function that checks if the button of emergency has been pressed.
 * In this case, the warning lights turn on and Arduino stops a second
 * (The action that follows the emergency button can be changed as you
 * wish, set a bigger stop or even sound the buzzer).
 */
void checkEmergency() {
  if (btn_stop) {
    Serial.println("!!!-----------------------!!!");
    Serial.println("!!!----EMERGENCY STOP!----!!!");
    Serial.println("!!!-----------------------!!!");
    digitalWrite(PIN_LIGHT_W1, HIGH);
    digitalWrite(PIN_LIGHT_W2, HIGH);
    /*
     * while(1){
     *   blink_lights();
     * }
    }*/
    delay(1000);
  }
}

/*
 * Function that checks if there is an obstacle near the car.
 * In this case, the car stops.
 */
void checkObstacle() {
  if (lever_d && dist < MAX_DIST_BRAKE && dist > MIN_DIST_BRAKE) {   //Allows backward
    Serial.println("!!!------------------------!!!");
    Serial.println("!!!----EMERGENCY BRAKE!----!!!");
    Serial.println("!!!------------------------!!!");
    analogWrite(PIN_ME, 0);
  }
}

/*
 * Function that checks the gear lever (D, N or R).
 */
void checkLever() {
  if (lever_d) {
    digitalWrite(PIN_M1, HIGH);
    digitalWrite(PIN_M2, LOW);
    digitalWrite(PIN_LIGHT_R1, LOW);
  } else if (lever_r) {
    digitalWrite(PIN_M1, LOW);
    digitalWrite(PIN_M2, HIGH);
    digitalWrite(PIN_LIGHT_R1, HIGH);
  } else {
    digitalWrite(PIN_M1, LOW);
    digitalWrite(PIN_M2, LOW);
    digitalWrite(PIN_LIGHT_R1, LOW);
  }
}

/*
 * Function that checks if a switch of lights or claxon have changed.
 */
void checkControls() {
  if ((sw_lights_auto && checkLightIntensity()) || sw_lights_on) {
    digitalWrite(PIN_LIGHT_F1, HIGH); // Front left headlights
    digitalWrite(PIN_LIGHT_F2, HIGH); // Front right headlights
    digitalWrite(PIN_LIGHT_B1, HIGH); // Back headlights
  } else {
    digitalWrite(PIN_LIGHT_F1, LOW);  // Front left headlights
    digitalWrite(PIN_LIGHT_F2, LOW);  // Front right headlights
    digitalWrite(PIN_LIGHT_B1, LOW);  // Back headlights
  }
  
  if (sw_warnings) {
    blink_lights();                   // Function that blink lights
  } else {
    digitalWrite(PIN_LIGHT_W1, LOW);  // Front left warning lights
    digitalWrite(PIN_LIGHT_W2, LOW);  // Front right warning lights
  }
  
  if (btn_claxon) {
    tone(PIN_CLAXON, FREC_CLAXON);    // Plays a frecuency in a pin
  } else {
    noTone(PIN_CLAXON);               // Stop the sound
  }
}

/*
 * Function that returns '1' if the light is lower than a threshold and '0' if the
 * light is higher than a threshold 
 */
bool checkLightIntensity() {
  return ldr > LDR_THRESHOLD ? LOW : HIGH;
}

/*
 * Function that turns on and off the warning lights with a certain frequency 
 */
void blink_lights() {
  unsigned long currentMillis = millis();
  if ((unsigned long)(currentMillis - prevMillisBlink) >= intervalWarn) {
    state_warning = !state_warning;
    digitalWrite(PIN_LIGHT_W1, state_warning);
    digitalWrite(PIN_LIGHT_W2, state_warning);
    prevMillisBlink = millis();
  }
}

/*
 * Function that checks if the data sent from the TX is in the correct set of ranges.
 */
bool check_values(int data[]) {
  if (data[0] >= MIN_MOTOR && data[0] <= MAX_MOTOR &&
      data[1] >= MIN_DIR && data[1] <= MAX_DIR &&
      data[2] >= MIN_YAW && data[2] <= MAX_YAW &&
      data[3] >= MIN_PITCH && data[3] <= MAX_PITCH) {
    // checking flags
    for (int i = 4; i < DATA_LENGTH-1; i++) {
      if (data[i] != DATA_LOW && data[i] != DATA_HIGH) {
        return false;
      }
    }
    return true;
  }
  return false;
}

/*
 * Function that converts the string sent from the TX to integers values 
 * and saves it in an array.
 */
void string_data(String sdata){
  for (int i = 0; i < DATA_LENGTH; i++) {
    int index = sdata.indexOf(separator);
    data[i] = sdata.substring(0, index).toInt();
    sdata = sdata.substring(index + 1);
  }
}

/*
 * Function that moves an  certain angle the servomotor.
 * This allows to not use the servo library and avoid interrups.
 */
void move_servo(int pin, int angle) {
   float pause;
   pause = angle * 2000.0/180.0 + 700;
   digitalWrite(pin, HIGH); 
   delayMicroseconds(pause);
   digitalWrite(pin, LOW);
   delayMicroseconds(25000-pause);
}

/*
 * Function that prints in the console all the necesary information for debug. 
 */
void printLogs() {
  Serial.print("motor: ");
  Serial.print(motor);
  Serial.print(", ");
  Serial.print("dir: ");
  Serial.print(dir);
  Serial.print(", ");
  Serial.print("yaw: ");
  Serial.print(c_yaw);
  Serial.print(", ");
  Serial.print("pitch: ");
  Serial.print(c_pitch);
  Serial.print(", ");
  Serial.print("D: ");
  Serial.print(lever_d);
  Serial.print(", ");
  Serial.print("R: ");
  Serial.print(lever_r);
  Serial.print(", ");
  Serial.print("l_on: ");
  Serial.print(sw_lights_on);
  Serial.print(", ");
  Serial.print("l_auto: ");
  Serial.print(sw_lights_auto);
  Serial.print(", ");
  Serial.print("warn: ");
  Serial.print(sw_warnings);
  Serial.print(", ");
  Serial.print("ultra: ");
  Serial.print(sw_ultrasonic);
  Serial.print(", ");
  Serial.print("stop: ");
  Serial.print(btn_stop);
  Serial.print(", ");
  Serial.print("claxon: ");
  Serial.print(btn_claxon);

  Serial.print(", ");
  Serial.print("dist: ");
  Serial.print(dist);
  Serial.print(", ");
  Serial.print("ldr: ");
  Serial.println(ldr);
}

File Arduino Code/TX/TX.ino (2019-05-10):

/*
 * ELCOche
 * 
 * This project has been created by:
 * - Mª del Pilar Aguilera Manzanera
 * - Enrique Calatayud Candelas
 * - Guillermo González Martín
 * - María Tejedor Rami
 * for the subject Electronica de Comunicaciones (ELCO) at Escuela Técnica Superior
 * de Ingenieros de Telecomunicación (ETSIT) in the universidad Politécnica de Madrid (UPM).
 *  
 * In this file you can find the code for the System transmitter (steering wheel, Throttle and VR glasses).
 * The refered components are:
 * - Arduino Mega
 * - Transmitter (o transceptor) of radio with serial communication
 * - Accelerometer (MPU6050)
 * - 2 potentiometer
 * - 4 buttons
 * - 3 switches spdt (2 positions)
 * - 2 switches spdt (3 positions)
 * - Joystick
 */

// Libraries  
#include <SoftwareSerial.h>
#include <MPU6050.h>
#include <LiquidCrystal.h> 

// Configuration
/*
 * You can change all the parameters of the TX in this section.
 */
#define SERIAL_BAUDRATE     9600
#define RADIO_BAUDRATE      57600
#define MIN_MOTOR           0
#define MAX_MOTOR           255
#define MIN_DIR             60
#define MAX_DIR             120
#define MIN_PEDAL           0
#define MAX_PEDAL           829
#define MIN_WHEEL           230
#define CEN_WHEEL           540
#define MAX_WHEEL           832
#define DATA_HIGH           3
#define DATA_LOW            2

#define COLS                20
#define ROWS                4
#define E                   50
#define RS                  52
#define D4                  48
#define D5                  46
#define D6                  44
#define D7                  42

#define PIN_RADIO_TX        10
#define PIN_RADIO_RX        11
#define PIN_MOTOR           A1
#define PIN_DIR             A0
#define PIN_JOY_X           A3
#define PIN_JOY_Y           A4
#define PIN_LEVER_D         53
#define PIN_LEVER_R         51
#define PIN_SW_LIGHTS_ON    41
#define PIN_SW_LIGHTS_AUTO  47
#define PIN_SW_WARNINGS     49
#define PIN_SW_ULTRASONIC   45
#define PIN_SW_CAM          43
#define PIN_BTN_STOP        35
#define PIN_BTN_CAL         39
#define PIN_BTN_CAL_MPU     37
#define PIN_BTN_CLAXON      31

LiquidCrystal lcd(E, RS, D4, D5, D6, D7);
SoftwareSerial radio(PIN_RADIO_TX, PIN_RADIO_RX);
MPU6050 mpu;

int motor, dir, c_yaw, c_pitch;
int lever_d, lever_r, sw_lights_on, sw_lights_auto, sw_warnings, sw_ultrasonic, sw_cam, btn_stop, btn_cal, btn_cal_mpu, btn_claxon;

float timeStep = 0.01;
float yaw = 0;
float pitch = 0;

String data = "";
String text_0 = "ELCOche - 2019";
String text_1, text_2, text_3;

void setup() {
   
  Serial.begin(SERIAL_BAUDRATE);
  radio.begin(RADIO_BAUDRATE);
  lcd.begin(COLS, ROWS);
  
  while(!mpu.begin(MPU6050_SCALE_2000DPS, MPU6050_RANGE_2G)) {
    Serial.println("Could not find a valid MPU6050 sensor, check wiring!");
    lcd.clear();
    lcd.setCursor(0, 0);
    lcd.print(text_0);
    lcd.setCursor(0, 2);
    lcd.print("MPU ERROR!");
    lcd.setCursor(0, 3);
    lcd.print("Please, check wiring");
    delay(500);
  }
  mpu.calibrateGyro();
  mpu.setThreshold(3); //Default: 3
  
  pinMode(PIN_MOTOR,              INPUT);
  pinMode(PIN_DIR,                INPUT);
  pinMode(PIN_JOY_X,              INPUT);
  pinMode(PIN_JOY_Y,              INPUT);
  pinMode(PIN_LEVER_D,            INPUT_PULLUP);
  pinMode(PIN_LEVER_R,            INPUT_PULLUP);
  pinMode(PIN_SW_LIGHTS_ON,       INPUT_PULLUP);
  pinMode(PIN_SW_LIGHTS_AUTO,     INPUT_PULLUP);
  pinMode(PIN_SW_WARNINGS,        INPUT_PULLUP);
  pinMode(PIN_SW_ULTRASONIC,      INPUT_PULLUP);
  pinMode(PIN_BTN_STOP,           INPUT_PULLUP);
  pinMode(PIN_BTN_CAL,            INPUT_PULLUP);
  pinMode(PIN_BTN_CAL_MPU,        INPUT_PULLUP);
  pinMode(PIN_BTN_CLAXON,         INPUT_PULLUP);
  pinMode(PIN_SW_CAM,             INPUT_PULLUP);
}

void loop() {
  /*
   * Getting yaw an pitch values from the accelerometer.
   */
  getYPR();

  /*
   * With the calibration data, defining the max turn for both directions of the steering 
   * wheel, in order to set the max value.
   */
  int max_turn = min(abs(MIN_WHEEL - CEN_WHEEL), abs(MAX_WHEEL - CEN_WHEEL));
  
  motor =           map(analogRead(PIN_MOTOR), MIN_PEDAL, MAX_PEDAL, MIN_MOTOR, MAX_MOTOR);
  dir =             map(analogRead(PIN_DIR), CEN_WHEEL - max_turn, CEN_WHEEL + max_turn, MIN_DIR, MAX_DIR);
  lever_d =         readValue(PIN_LEVER_D);
  lever_r =         readValue(PIN_LEVER_R);
  sw_lights_on =    readValue(PIN_SW_LIGHTS_ON);
  sw_lights_auto =  readValue(PIN_SW_LIGHTS_AUTO);
  sw_warnings =     readValue(PIN_SW_WARNINGS);
  sw_ultrasonic =   readValue(PIN_SW_ULTRASONIC);
  sw_cam =          readValue(PIN_SW_CAM);
  btn_stop =        readValue(PIN_BTN_STOP);
  btn_cal =         readValue(PIN_BTN_CAL);
  btn_cal_mpu =     readValue(PIN_BTN_CAL_MPU);
  btn_claxon =      readValue(PIN_BTN_CLAXON);

  /*
   * If the value of the pedal potentiometer is very low, ignore it.
   */
  if (motor < 5) {
    motor = 0;
  }

  /*
   * dir (direction) can´t be out of the definited range.
   */
  if (dir > MAX_DIR) {
    dir = MAX_DIR;
  } else if (dir < MIN_DIR) {
    dir = MIN_DIR;
  }

  /*
   * If the switch that checks the cam mode is in joystick mode, map the analog inputs 
   * of the joystick. If it is in VR mode, map the yaw and pitch values sent from the 
   * accelerometer. 
   */
  if (sw_cam == DATA_LOW) {
    c_yaw =         map(analogRead(PIN_JOY_X), 0, 1023, 0, 180);
    c_pitch =       map(analogRead(PIN_JOY_Y), 1023, 0, 0, 180);
  } else {
    c_yaw =         map(yaw, -10, 10, 0, 180);
    c_pitch =       map(pitch, -10, 10, 0, 180);
  }
  
  sendData();
  printLogs();
  printLCD();

  if (btn_cal_mpu == DATA_HIGH){
    Serial.println("Calibrado de MPU");
    // It doesn´t work very well...
    mpu.calibrateGyro();
    mpu.setThreshold(3); //Default: 3
  }
  delay(50);
}

/*
 * Function that converts '1' and '0 to another integer values.
 */
int readValue(int pin) {
  return digitalRead(pin) ? DATA_LOW : DATA_HIGH;
}

/*
 * Function that creates the data string that is sent to the RX. 
 */
void sendData() {
  data = "";
  data += String(motor);
  data += ",";
  data += String(dir);
  data += ",";
  data += String(c_yaw);
  data += ",";
  data += String(c_pitch);
  data += ",";
  data += String(lever_d);
  data += ",";
  data += String(lever_r);
  data += ",";
  data += String(sw_lights_on);
  data += ",";
  data += String(sw_lights_auto);
  data += ",";
  data += String(sw_warnings);
  data += ",";
  data += String(sw_ultrasonic);
  data += ",";
  data += String(btn_stop);
  data += ",";
  data += String(btn_claxon);
  radio.print("s" + data + "e");
}
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

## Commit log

2019-05-10 Lacking documents
    [adaptador.stl, base.stl, brazo.stl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]
2019-05-12 Web acabada si que si
